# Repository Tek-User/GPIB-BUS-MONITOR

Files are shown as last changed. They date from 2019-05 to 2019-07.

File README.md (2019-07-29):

# GPIB-BUS-MONITOR

This is an Arduino project.  The program uses two GPIB bus monitoring strategies to watch traffic on the bus.  It can be a Sniffer where it is as close to invisible to the bus as possible.  Or it can be a Listener which actively participates on the bus for listening purposes.  The Arduino platform with minimal hardware as a "listener" can support only a few other devices on the bus because it has current limits on pulling-down the bus when asserting a signal.

Both strategies were tested with two other devices on the bus:  a National Instruments GPIB controller card and a Tektronix 2440 DSO oscilloscope and both techniques functioned well.

The hardware used is an Arduino Nano.  It has enough IO to manage all 16 GPIB signals.

Included in this project is an EAGLE PCB design to connect the Nano to a GPIB header.  You can use a Centronics style GPIB connector or simply hand solder all the GPIB wires directly to the PCB.

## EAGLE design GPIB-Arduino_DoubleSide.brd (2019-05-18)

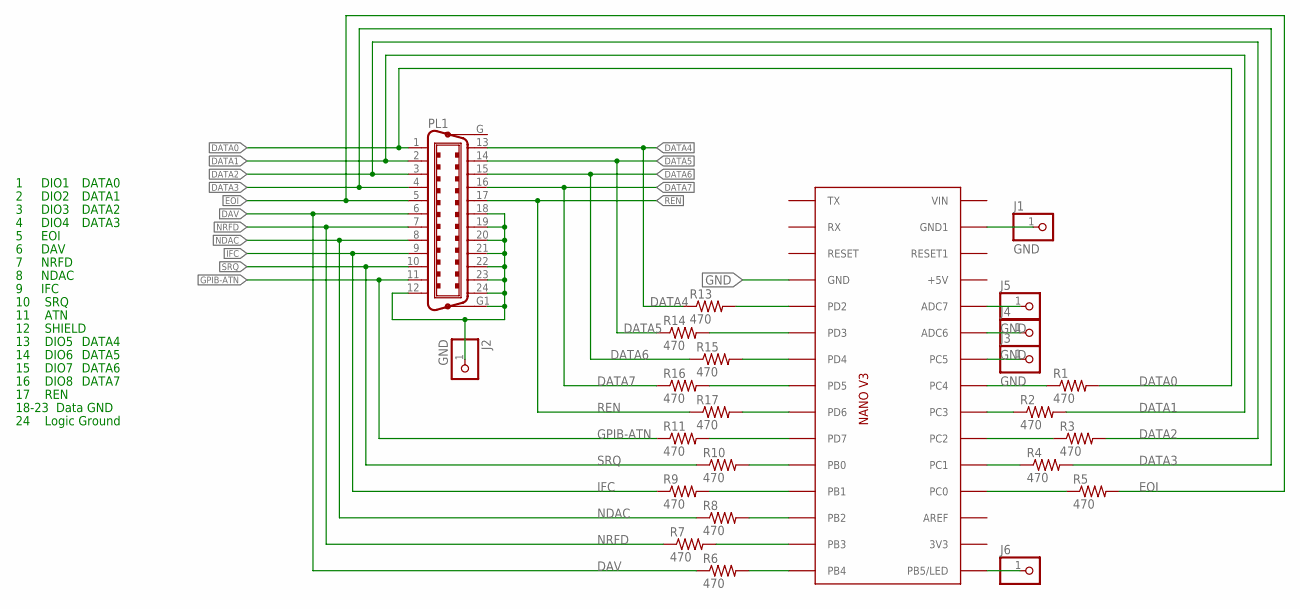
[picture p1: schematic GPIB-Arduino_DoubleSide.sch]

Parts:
J1, J2, J3, J4, J5: GND; 1X01_ROUND
J6: PINHD1X01ROUND; 1X01_ROUND
PL1: C24HP; 24HP
R1, R2, R3, R4, R5, R6, R7, R8, R9, R10, R11, R13, R14, R15, R16, R17: 470; R-1/8W
U$6: ARDUINONANO; PDIP-32

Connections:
DATA0: PL1.1, R1.2
DATA1: PL1.2, R2.2
DATA2: PL1.3, R3.2
DATA3: PL1.4, R4.2
DATA4: PL1.13, R13.1
DATA5: PL1.14, R14.1
DATA6: PL1.15, R15.1
DATA7: PL1.16, R16.1
DAV: PL1.6, R6.1
EOI: PL1.5, R5.2
GND: J1.1, J2.1, PL1.12, PL1.18, PL1.19, PL1.20, PL1.21, PL1.22, PL1.23, PL1.24, PL1.G1, U$6.GND, U$6.GND1
GPIB-ATN: PL1.11, R11.1
IFC: PL1.9, R9.1
unnamed: R1.1, U$6.A3 (PC4)
unnamed: R2.1, U$6.A4 (PC3)
unnamed: R3.1, U$6.A5 (PC2)
unnamed: R4.1, U$6.A6 (PC1)
unnamed: R5.1, U$6.A7 (PC0)
unnamed: R11.2, U$6.D7
unnamed: R10.2, U$6.D8 (PB0)
unnamed: R9.2, U$6.D9 (PB1)
unnamed: R8.2, U$6.D10 (PB2)
unnamed: R7.2, U$6.D11 (PB3)
unnamed: R6.2, U$6.D12 (PB4)
unnamed: J5.1, U$6.A0 (ADC7)
unnamed: R13.2, U$6.D2
unnamed: R14.2, U$6.D3
unnamed: R15.2, U$6.D4
unnamed: R16.2, U$6.D5
unnamed: R17.2, U$6.D6
unnamed: J4.1, U$6.A1 (ADC6)
unnamed: J3.1, U$6.A2 (PC5)
unnamed: J6.1, U$6.D13 (PB5/LED)
NDAC: PL1.8, R8.1
NRFD: PL1.7, R7.1
REN: PL1.17, R17.1
SRQ: PL1.10, R10.1

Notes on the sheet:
1 DIO1
2 DIO2
3 DIO3
4 DIO4
5 EOI
6 DAV
7 NRFD
8 NDAC
9 IFC
10 SRQ
11 ATN
12 SHIELD
13 DIO5
14 DIO6
15 DIO7
16 DIO8
17 REN
18-23 Data GND
24 Logic Ground
DATA0
DATA1
DATA2
DATA3
DATA4
DATA5
DATA6
DATA7

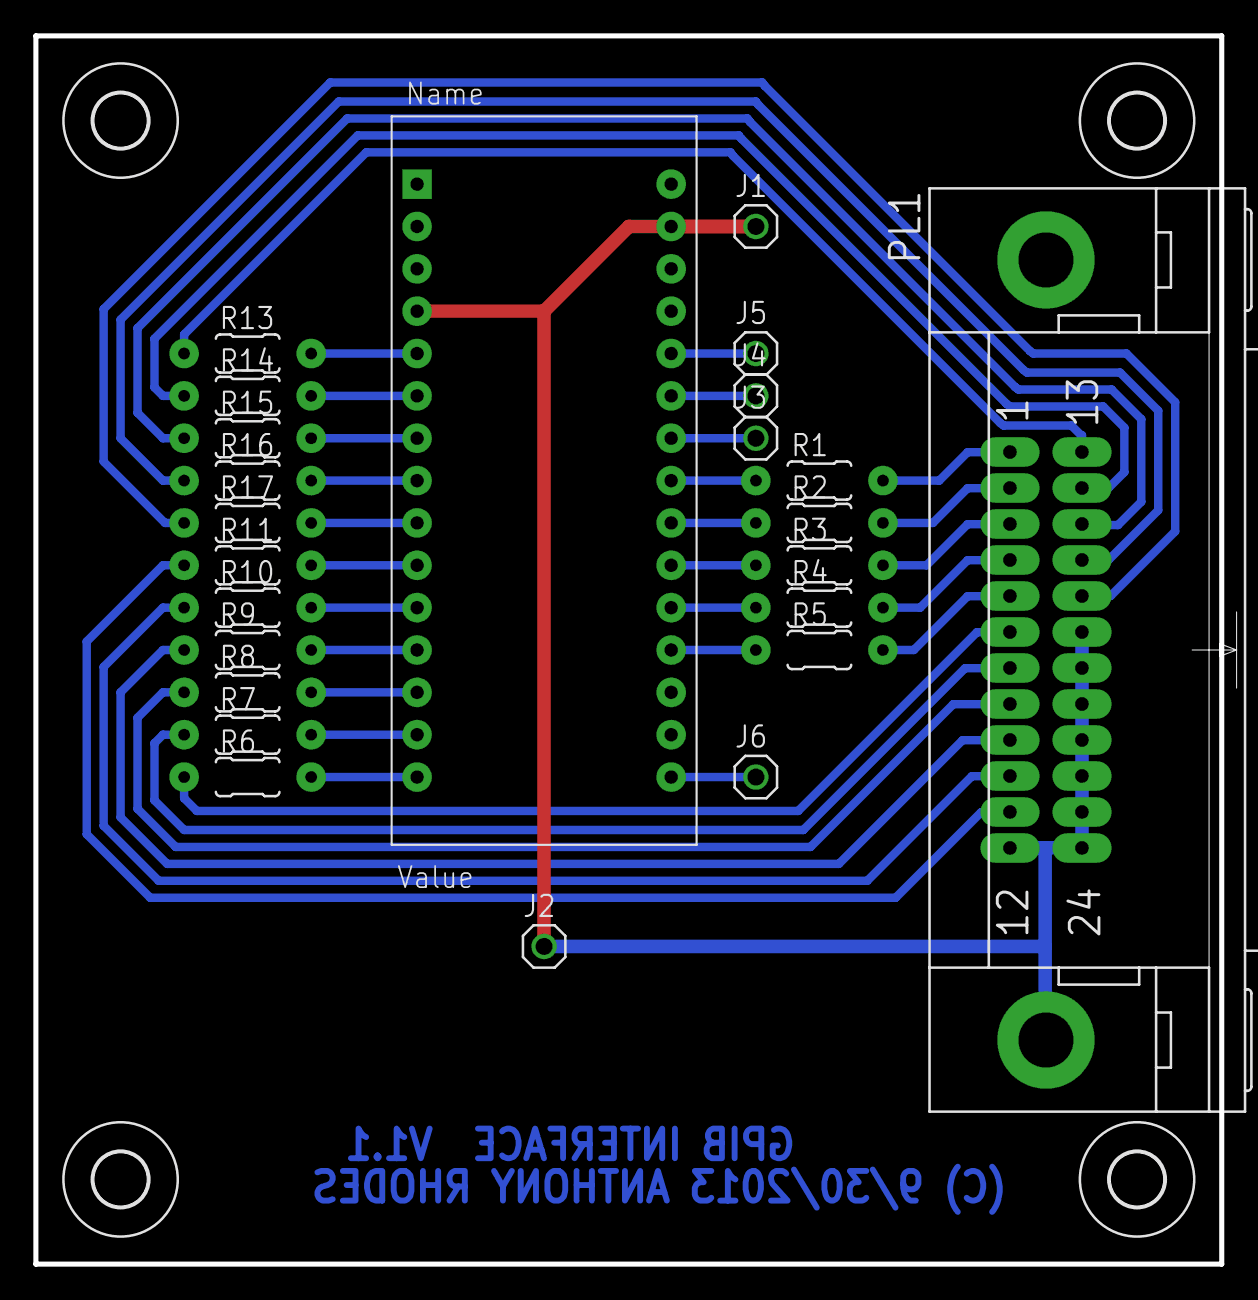
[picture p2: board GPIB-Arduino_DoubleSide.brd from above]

Board: 2 copper layers, 71.1 x 73.7 mm, 28 parts (0 on the bottom side), 37 nets.

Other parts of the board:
U$1, U$2, U$3, U$5: 3,2

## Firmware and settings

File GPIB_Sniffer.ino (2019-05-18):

#include <avr/pgmspace.h>
#include <stdlib.h>
#include <inttypes.h>
#include <stdint.h>
#include <stdbool.h>
#include "gpib.h"
#include "Arduino.h"




// GPIB Monitor:
//Strategy #1:  Sniffer:  Should be as close to invisible to the bus as possible.
// All pins should be input-tristate.
// EXCEPT:
// DAV, pin should be input-pullup (equivalent to de-asserted) so there is no spurious noise on the pin.

// Strategy #2 be a standard listener...

//Define monitoring strategy:  Pick ONE:  Uncomment one and comment-out the other
#define SNIFFER
//#define LISTENER



void setup() {
  Serial.begin(115200);
  
  #ifdef SNIFFER
    GPIBInitSniff();
  #else
    #ifdef LISTENER
      GPIBInitListen();
    #else
      #error MUST DEFINE EITHER SNIFFER OR LISTENER
    #endif
  #endif



}


#ifdef SNIFFER
void loop() {
  long counter= 0;

//  monitor for a byte coming in and send it to the serial port:
//  wait for DAV to be asserted, then read the data, then wait for DAV to be de-asserted
//  then repeat....

  while(!GPIBDataReady()){   //wait for data  to be ready on the bus
     counter++;
     if (counter > 12000000l) {
         Serial.println(F("Waiting..."));
         counter = 0;
     } // end if
  }  // end while
  counter = 0;
  Serial.write(GPIBReadByte()); //read and send the data
  if ((EOI_PIN & EOI_BIT) == 0) Serial.println();  //send new line if it id the end of a message
  while (GPIBDataReady()); // wait for the data to be finished

  
} //end loop
#endif




#ifdef LISTENER
void loop() {
  GPIBMonitor();
}
#endif

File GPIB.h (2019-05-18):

#ifndef GPIB_h
#define GPIB_h

#include <inttypes.h>
#include <stdint.h>
#include <stdbool.h>

// PIN DEFINITIONS
#define _HIGH    1
#define _LOW     0
#define _ASSERTED  0
#define _RELEASED  1

//0=C4    4=C2
//1=c1    5=C1
//2=C    6=D3
//3=D4    7=D5

#if defined (ARDUINO_AVR_UNO) || defined (ARDUINO_AVR_NANO)
#warning "UNO or Nano"
    //#Define DATA0 C.4
    #define DATA0_PORT PORTC
    #define DATA0_PIN PINC
    #define DATA0_DDR DDRC
    #define DATA0_BIT _BV(4)

    //#Define DATA1 C.3
    #define DATA1_PORT PORTC
    #define DATA1_PIN PINC
    #define DATA1_DDR DDRC
    #define DATA1_BIT _BV(3)

    //#Define DATA2 C.2
    #define DATA2_PORT PORTC
    #define DATA2_PIN PINC
    #define DATA2_DDR DDRC
    #define DATA2_BIT _BV(2)

    //#Define DATA3 C.1
    #define DATA3_PORT PORTC
    #define DATA3_PIN PINC
    #define DATA3_DDR DDRC
    #define DATA3_BIT _BV(1)

    //#Define DATA4 D.2
    #define DATA4_PORT PORTD
    #define DATA4_PIN PIND
    #define DATA4_DDR DDRD
    #define DATA4_BIT _BV(2)

    //#Define DATA5 D.3
    #define DATA5_PORT PORTD
    #define DATA5_PIN PIND
    #define DATA5_DDR DDRD
    #define DATA5_BIT _BV(3)

    //#Define DATA6 D.4
    #define DATA6_PORT PORTD
    #define DATA6_PIN PIND
    #define DATA6_DDR DDRD
    #define DATA6_BIT _BV(4)

    //#Define DATA7 D.5
    #define DATA7_PORT PORTD
    #define DATA7_PIN PIND
    #define DATA7_DDR DDRD
    #define DATA7_BIT _BV(5)
    
    //#Define REN   D.6
    #define REN_PORT PORTD
    #define REN_PIN PIND
    #define REN_DDR DDRD
    #define REN_BIT _BV(6)
    
    //#Define ATN   D.7
    #define ATN_PORT PORTD
    #define ATN_PIN PIND
    #define ATN_DDR DDRD
     #define ATN_BIT _BV(7)

    //#Define SRQ   B.0
    #define SRQ_PORT PORTB
    #define SRQ_PIN PINB
    #define SRQ_DDR DDRB
    #define SRQ_BIT _BV(0)
  
    //#Define IFC   B.1
    #define IFC_PORT PORTB
    #define IFC_PIN PINB
    #define IFC_DDR DDRB
    #define IFC_BIT _BV(1)

    //#Define NDAC  B.2
    #define NDAC_PORT PORTB
    #define NDAC_PIN PINB
    #define NDAC_DDR DDRB
    #define NDAC_BIT _BV(2)

    //#Define NRFD  B.3
    #define NRFD_PORT PORTB
    #define NRFD_PIN PINB
    #define NRFD_DDR DDRB
    #define NRFD_BIT _BV(3)

    //#Define DAV   B.4
    #define DAV_PORT PORTB
    #define DAV_PIN PINB
    #define DAV_DDR DDRB
    #define DAV_BIT _BV(4)

    //#Define EOI   C.0
    #define EOI_PORT PORTC
    #define EOI_PIN PINC
    #define EOI_DDR DDRC
    #define EOI_BIT _BV(0)

    //#Define LED   B.5
    #define LED_PORT PORTB
    #define LED_PIN PINB
    #define LED_DDR DDRB
    #define LED_BIT _BV(5)

    //#Define FREE  C.5
    #define CS_PIN 10   //using the SD shield, it uses pin 10 for the card select.


#elif defined(ARDUINO_AVR_MEGA) || defined(ARDUINO_AVR_MEGA2560)  
     //#Define DATA0 A.0
    #define DATA0_PORT PORTA
    #define DATA0_PIN PINA
    #define DATA0_DDR DDRA
    #define DATA0_BIT _BV(0)

    //#Define DATA1 A.2
    #define DATA1_PORT PORTA
    #define DATA1_PIN PINA
    #define DATA1_DDR DDRA
    #define DATA1_BIT _BV(2)

    //#Define DATA2 A.4
    #define DATA2_PORT PORTA
    #define DATA2_PIN PINA
    #define DATA2_DDR DDRA
    #define DATA2_BIT _BV(4)

    //#Define DATA3 A.6
    #define DATA3_PORT PORTA
    #define DATA3_PIN PINA
    #define DATA3_DDR DDRA
    #define DATA3_BIT _BV(6)

    //#Define DATA4 A.1
    #define DATA4_PORT PORTA
    #define DATA4_PIN PINA
    #define DATA4_DDR DDRA
    #define DATA4_BIT _BV(1)

    //#Define DATA5 A.3
    #define DATA5_PORT PORTA
    #define DATA5_PIN PINA
    #define DATA5_DDR DDRA
    #define DATA5_BIT _BV(3)

    //#Define DATA6 A.5
    #define DATA6_PORT PORTA
    #define DATA6_PIN PINA
    #define DATA6_DDR DDRA
    #define DATA6_BIT _BV(5)

    //#Define DATA7 A.7
    #define DATA7_PORT PORTA
    #define DATA7_PIN PINA
    #define DATA7_DDR DDRA
    #define DATA7_BIT _BV(7)

    //#Define REN   C.6
    #define REN_PORT PORTC
    #define REN_PIN PINC
    #define REN_DDR DDRC
    #define REN_BIT _BV(6)
    
    //#Define ATN   C.1
    #define ATN_PORT PORTC
    #define ATN_PIN PINC
    #define ATN_DDR DDRC
     #define ATN_BIT _BV(1)

    //#Define SRQ   C.0
    #define SRQ_PORT PORTC
    #define SRQ_PIN PINC
    #define SRQ_DDR DDRC
    #define SRQ_BIT _BV(0)
  
    //#Define IFC   C.3
    #define IFC_PORT PORTC
    #define IFC_PIN PINC
    #define IFC_DDR DDRC
    #define IFC_BIT _BV(3)

    //#Define NDAC  C.2
    #define NDAC_PORT PORTC
    #define NDAC_PIN PINC
    #define NDAC_DDR DDRC
    #define NDAC_BIT _BV(2)

    //#Define NRFD  C.5
    #define NRFD_PORT PORTC
    #define NRFD_PIN PINC
    #define NRFD_DDR DDRC
    #define NRFD_BIT _BV(5)

    //#Define DAV   C.4
    #define DAV_PORT PORTC
    #define DAV_PIN PINC
    #define DAV_DDR DDRC
    #define DAV_BIT _BV(4)

    //#Define EOI   C.7
    #define EOI_PORT PORTC
    #define EOI_PIN PINC
    #define EOI_DDR DDRC
    #define EOI_BIT _BV(7)

    //#Define LED   B.7
    #define LED_PORT PORTB
    #define LED_PIN PINB
    #define LED_DDR DDRB
    #define LED_BIT _BV(7)

    //Define SwitchSense  L.4
    #define SENSE_PORT PORTL
    #define SENSE_PIN PINL
    #define SENSE_DDR DDRL
    #define SENSE_BIT _BV(4)

    //Define SwitchPoll1  L.3
    #define SPOLL1_PORT PORTL
    #define SPOLL1_PIN PINL
    #define SPOLL1_DDR DDRL
    #define SPOLL1_BIT _BV(3)

    //Define SwitchPoll2  L.2
    #define SPOLL2_PORT PORTL
    #define SPOLL2_PIN PINL
    #define SPOLL2_DDR DDRL
    #define SPOLL2_BIT _BV(2)

    //Define SwitchPoll3  L.1
    #define SPOLL3_PORT PORTL
    #define SPOLL3_PIN PINL
    #define SPOLL3_DDR DDRL
    #define SPOLL3_BIT _BV(1)

    //Define SwitchPoll4  L.0
    #define SPOLL4_PORT PORTL
    #define SPOLL4_PIN PINL
    #define SPOLL4_DDR DDRL
    #define SPOLL4_BIT _BV(0)

    //SD card defines
    #define CS_PIN  53    //using the standard SPI pins on the Mega double row header, card select is pin 53
    //#define CS_PIN  10
    //#define MOSI_PIN  51  //PIN_SPI_MOSI
    //#define MISO_PIN 50   //PIN_SPI_MISO predefined value
    //#define SCK_PIN 52    //SCK_PIN is predefined!



#else
    #error "NO CPU DEFINED!!"
#endif



//#define DMASK 0x3C  //'0011-1100  'data high nibble shifted right 2
//#define CMASK 0x1e  //'0001-1110  'data low nibble shifted left 1





// SPECIAL CHARACTERS
#define _CR    13
#define _LF    10
#define _ESC   27
#define _PLUS  43


#define ClientADDR 1  //GPIB address of the clinet
#define UNL 0x3F //=63d
#define UNT 0x5F 
#define TADDR 64
#define LADDR 32


//GLOBAL DATA
//uint8_t receiveState = 0;     //for state machine of receive GPIB data
//bool receivingData  = false;   //indicates GPIB receive is in progress




//Dim CFlip as ByteVectorData ({
//  &H00, &H08, &H04, &H0C
//  &H02, &H0A, &H06, &H0E
//  &H01, &H09, &H05, &H0D
//  &H03, &H0B, &H07, &H0F
//})
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
